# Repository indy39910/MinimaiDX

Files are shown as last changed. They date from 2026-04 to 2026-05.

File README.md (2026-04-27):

# MinimaiDX
### 8 Button AstroDX controller for tablet-sized devices using keyboard inputs

WhatsApp Image 2026-04-27 at 14 43 16 (1)
WhatsApp Image 2026-04-27 at 14 43 16 (2)
WhatsApp Image 2026-04-27 at 14 43 17 (1)
These are older photos not yet using the Pi Pico, the newer version has a smaller and more compact dongle

WhatsApp Image 2026-04-27 at 14 43 16

Features
- Adaptable to various sized tabets
- Minimal hardware needed (no pcbs needed)
- Very cheap to make
- No screws required at all
- Cut filament is used as hinges

Material list
- 30 AWG wire
- 8 Low profile Kalih Red switches
- Raspberry Pi Pico (I recommend getting a knockoff with usb-c preinstalled)
- 3d printer filament of any color (I used transparent PETG)

Notes
- Basic soldering skills are needed (this was my first time soldering in a project)
- a 3d printer is needed (preferibly with a print area of 220mmx220mm or larger)
- a working tablet that supports usb host mode (if not a OTG adapter will be required)
- Most likely will need to modify some of my CAD files to make the mounting clips fit your tablet 
- i'll be honest this project is fundimentally super simple but i spent way too long trying to perfect as many things as i could. However, I am a student can do mediocre CAD at best so if you want to scale up/down the CAD files to fit your tabet size you **will** need to edit the slots for the switches and holes for hinges

- if you dont know how to edit CAD files you can also contact my discord (invisble.) and subject to my avaiblity i might be able to help you

The original design was made to perfectly fit my iPad Air (3rd generation)
You will most likely have a differently sized device, and thus will need to modify my design files

## About the License

It's CC-NC. So DIY for yourself and for your friend for free, don't make money from it. And plagiarism that doesn’t mention the original author is not acceptable.

If you're interested in buying from me or some kind of commercial use, please contact me (Discord).
Discord username - invisble.

## Disclaimer

This is a personal project I did on my own time without any endorsement, i will continue to listen to feedback and potentially improve this project. I try my best to ensure everything is working and accurate. However, mistakes may occour I cannot be held responsible for any loss of your time or money that may result from using this project. Thank you for your understanding.

# Build guide here
[(Build guide.md)](https://github.com/osume-code/MinimaiDX/blob/main/Build%20guide.md)

Shield: [][cc-by-nc]

This work is licensed under a
[Creative Commons Attribution-NonCommercial 4.0 International License][cc-by-nc].

[][cc-by-nc]

[cc-by-nc]: https://creativecommons.org/licenses/by-nc/4.0/
[cc-by-nc-image]: https://licensebuttons.net/l/by-nc/4.0/88x31.png
[cc-by-nc-shield]: https://img.shields.io/badge/License-CC%20BY--NC%204.0-lightgrey.svg

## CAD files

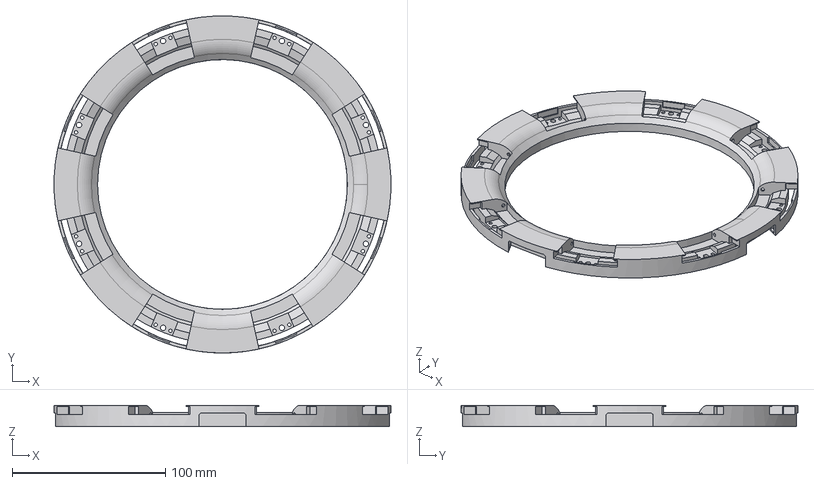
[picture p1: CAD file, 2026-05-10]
CAD files/Minimai.step
219.8 x 219.9 x 14.0 mm

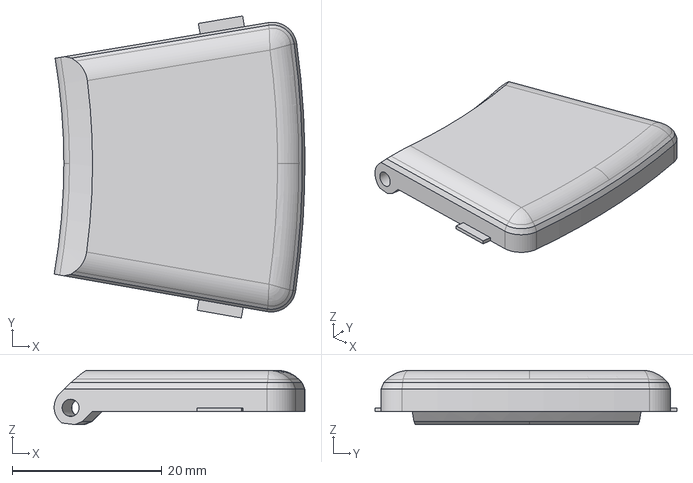
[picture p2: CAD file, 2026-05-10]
CAD files/Minimai Button.step
33.5 x 40.4 x 7.24 mm

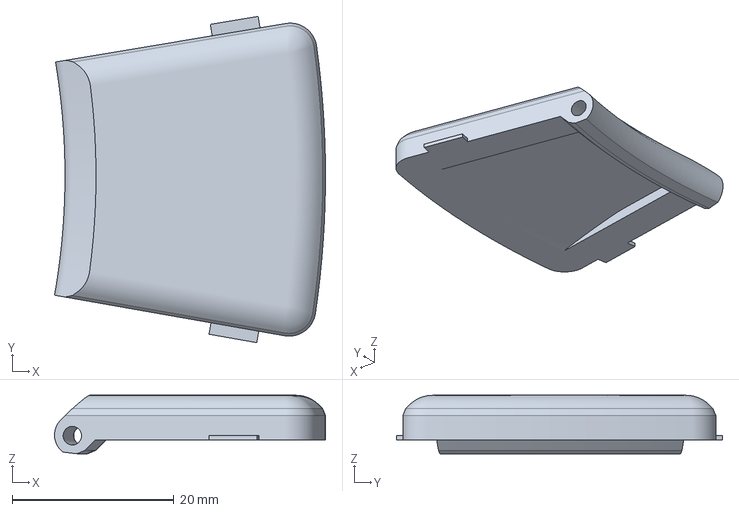
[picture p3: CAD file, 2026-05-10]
Print files/Minimai Buttons.3mf
33.5 x 40.4 x 7.24 mm

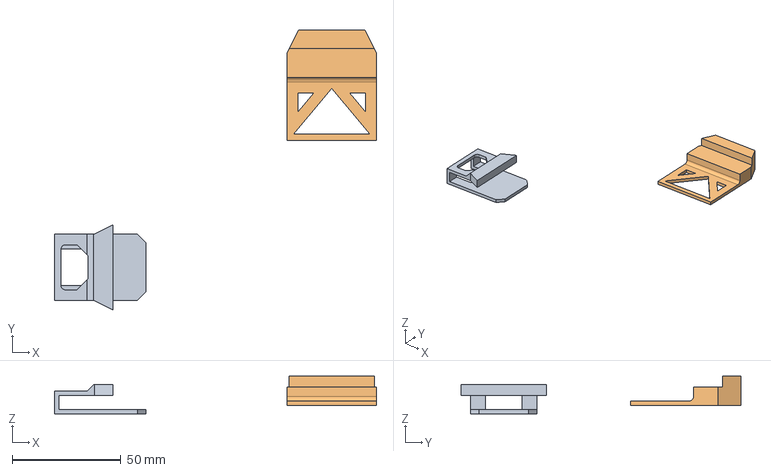
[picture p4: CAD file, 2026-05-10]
CAD files/Minimai Clips.step
147.9 x 128.5 x 17.4 mm

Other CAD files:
Print files/Minimai Shell.3mf
Print files/Minimai Clips.3mf

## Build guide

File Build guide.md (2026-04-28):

# Build Guide

Firstly we need to determine the size/play area of your tablet (mine is about 163mm) to do this open up AstroDX and load up a chart, then measure the diameter of the play circle. You may be able to adjust the play area size in settings to match mine in order to not need any CAD modifications (at least for the shell)
playareasize
Mounting clips will also need to be custom made for different sized tablets (CAD files attached) modify as needed

## 3d printing instructions
- Ensure the printed switch socket fits the low profile switch snugly but it should not take too much force
- Make sure you can fit 1.75mm filament through the holes in the printed buttons and shell
- I recommend printing the buttons in lower layer heights (0.10mm)
- I also recommend printing the buttons top down and use a smooth plate if possible
- For best feel calibrate ironing and turn topmost surface ironing on for the shell
- No supports are needed for any of the 3d prints

# How to assemble 
## Wiring 

Assuming you want the wires to come out from the top (I reccomend either going with top or bottom relative to play orientation) ring buttons 1-4 will be clumped together and 5-8 will also be clumped together on the other side. Photo for visualisation 

In total 8 pairs of wires will be needed with 4 pairs per side, you want to make sure that you can identify which pair of wires orginate from the same switch (I did this by pulling back the wire from the cable channel until I could see a pair have a visbly different length from the others). In each of the sides, each pair of wires will need to be linearly longer as more cable is needed to reach the Pi Pico (so for example the pair of wires closest to the designated hole lets say button1 that the wires will come out off will have the shortest wire and button4 will need the longest pair of wires)
First start with soldering switches to the their respective wires
- make 4 sets of a pair of wires
- recommened to tin the tip of the wires with solder before soldering it to the switch
- solder the wires to the switches
Now we add the switches to the shell
- thread the wires into the cable channel
- then insert the switches into the slot
- now thread the wires through the little holes until you reach your exit point
- repeat increasing wire length until all 4 buttons on that side are done
Repeat again for all the buttons on the other side

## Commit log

2026-04-27 Update README with project details and requirements
    Added features, material list, and requirements for the project.
2026-04-27 Revise README with material list and build guide
    Updated material list and added notes on project requirements. Included a new build guide section with instructions for determining tablet size.
2026-04-27 Enhance build guide with 3D printing and wiring details
    Added detailed 3D printing instructions and assembly guidelines for wiring, including recommendations for print settings and wire management.

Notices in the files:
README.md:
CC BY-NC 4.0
